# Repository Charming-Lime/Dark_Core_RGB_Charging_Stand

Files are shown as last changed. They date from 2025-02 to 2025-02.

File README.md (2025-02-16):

# Corsair Dark Core RGB Pro SE Wireless Charging Stand 
A RGB wireless charging stand for the Corsair Dark Core RGB Pro SE.

[](photos/photo1.jpg)

Designed to be printed with a single manual filament swap for the diffuser ring. 

Printed in Polymaker PolyTerra charcoal matte PLA and SUNLU transparent PLA. 

# Materials

Links are for example purposes and generics should be available from the usual amazon / ebay / Aliexpress.

## Required 
* Generic Wireless charger PCB, there are many listings on amazon and Aliexpress with the same dimensions that will work

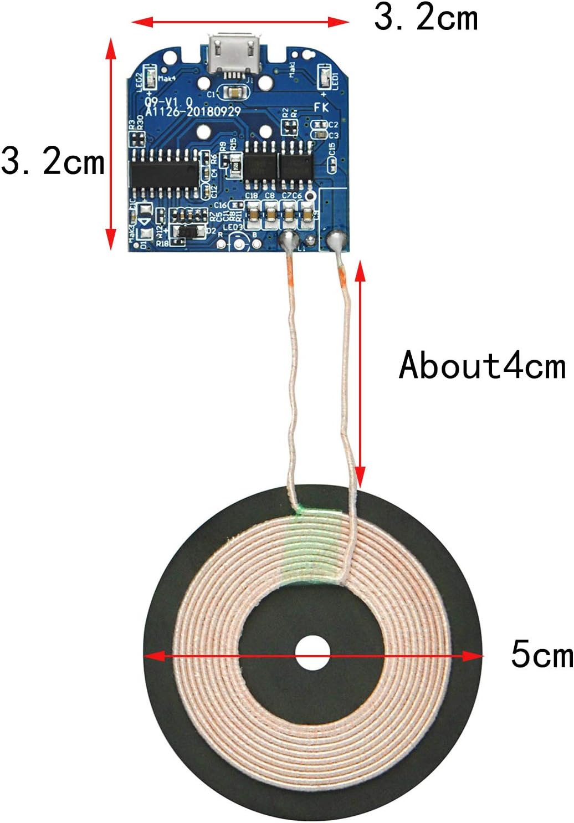
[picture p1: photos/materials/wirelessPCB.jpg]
  [](https://www.amazon.com/dp/B073W7P5T8?ref=ppx_yo2ov_dt_b_fed_asin_title)

* RP2040-zero

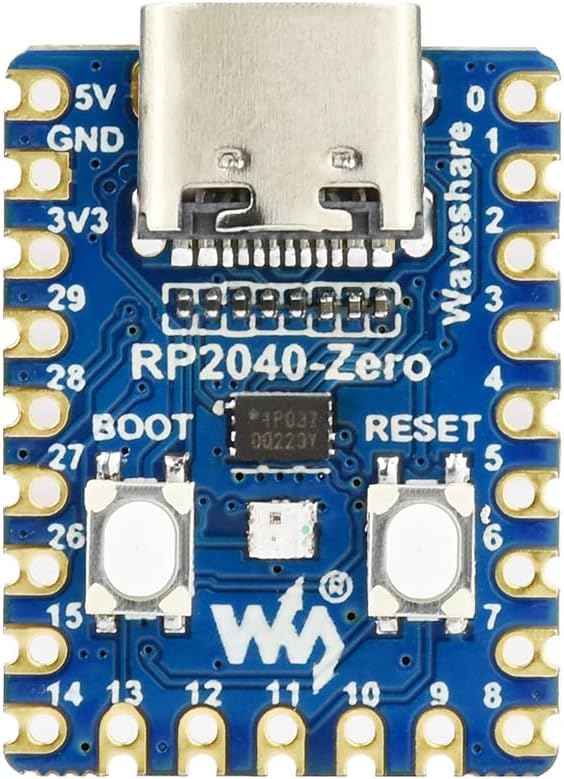
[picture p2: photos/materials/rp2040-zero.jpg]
  [](https://www.amazon.com/RP2040-Zero-High-Performance-Microcontroller-Castellated-Applications/dp/B09KZPCNPL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)
  
* USB C Fast Charge Decoy Trigger PCB set at 5V
  
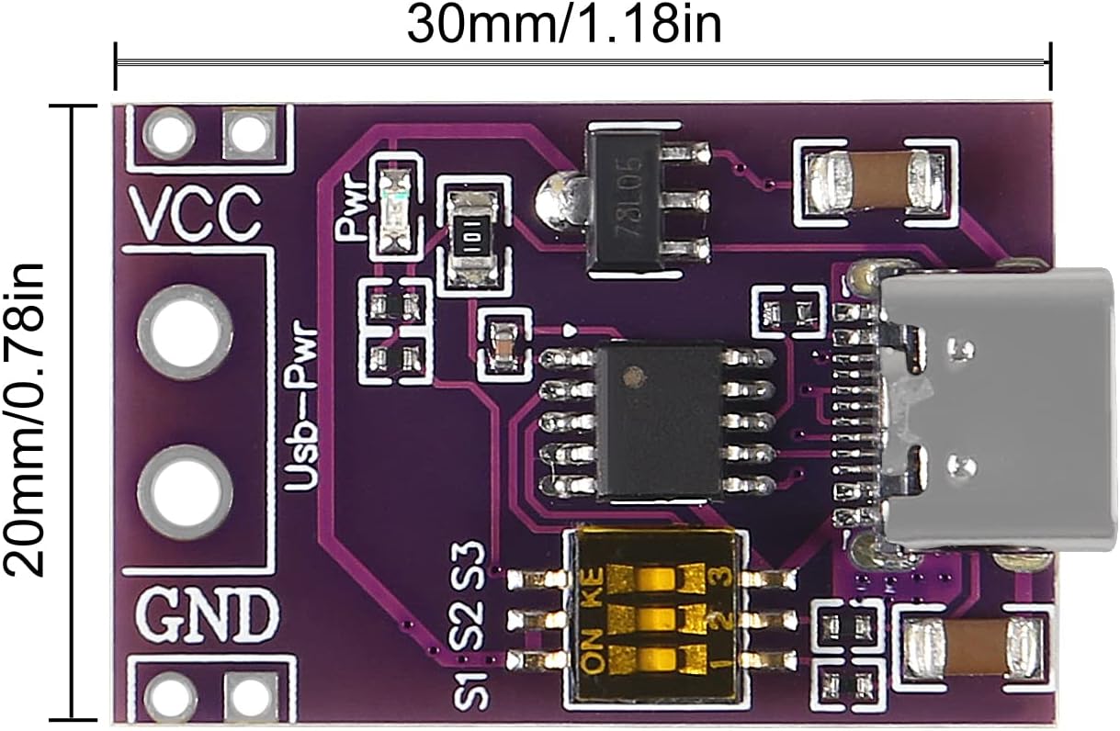
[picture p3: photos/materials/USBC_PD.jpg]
  [](https://www.amazon.com/dp/B0BTHXKM91?ref=ppx_yo2ov_dt_b_fed_asin_title)

* 5v WS2812b RGB strip, 60 LEDs/meter, cut to 18 segments
  
* Wire, heat shrink, soldering equipment
  
* 4x m3x16 self taping screws
* Stick on rubber feet.

Most of the components should be generic enough that the exact seller should not matter, but I have included exactly what I used anyway. Room is tight and most components are sized to fit snugly.

### Optional
* 10k and 20k resistor for voltage divider if you want the RGB to react while charging.
  *  Required if you want the LED on the stand to pulse when the mouse is charging.
* Hot glue
* CA glue
 
# Assembly
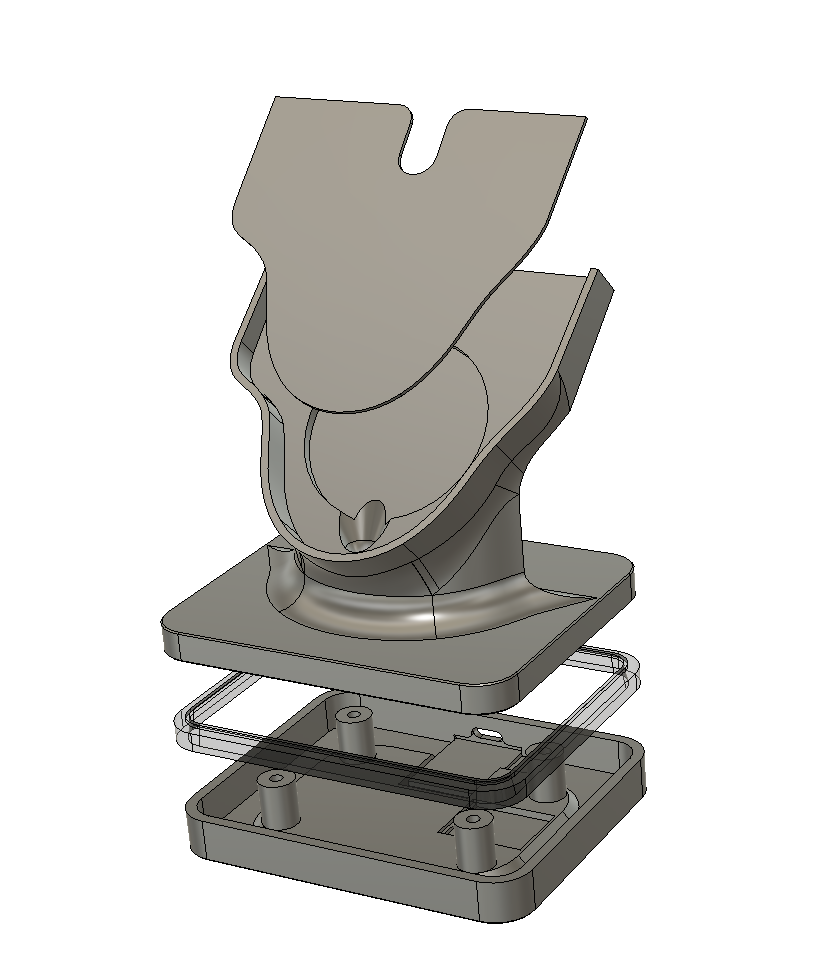
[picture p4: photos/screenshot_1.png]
[](photos/screenshot_1.png)
## Printing

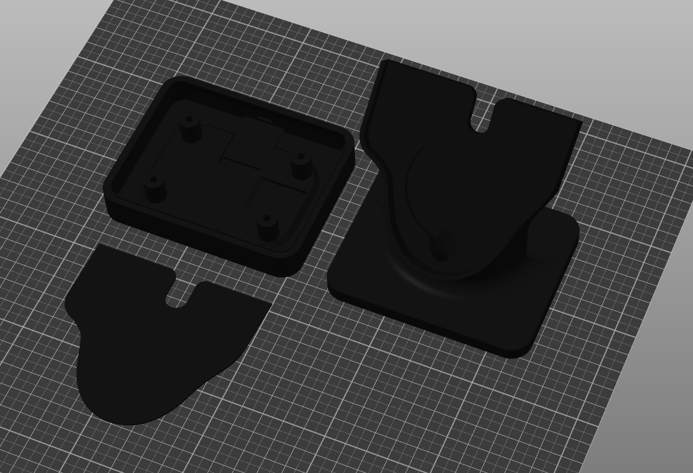
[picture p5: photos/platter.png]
[](photos/platter.png)

The charging stand is printed in 3 pieces, stand, base, and cover, I used 0.16 layer height. 
Part orientation should be as imported into the slicer. The base and diffuser get imported and sliced together, with a pause and filament swap at ~11.50mm.
Print with supports on for the holder and base. Set your support settings so the only part with supports is the cutout and screw holes. You *may* be able to get away without it depending on how good your printer is at bridging.

 ### Base
The part where the magic happens.
Transparent filament works the best for the diffuser, but a white filament should work. 
Import both the base and the diffuser and slice them together. Insert a pause command or a filament swap at 11.50mm. Be sure to thoroughly purge and clean your nozzle. If your slicer supports it change the settings for the diffuser to be no infill, 2 perimeters, and 0.2 layer height, but feel free to experiment. You are trying to strike a ballance between seeing the individual LEDs and letting light though. This 
will give you the most even defusing.

## Wiring
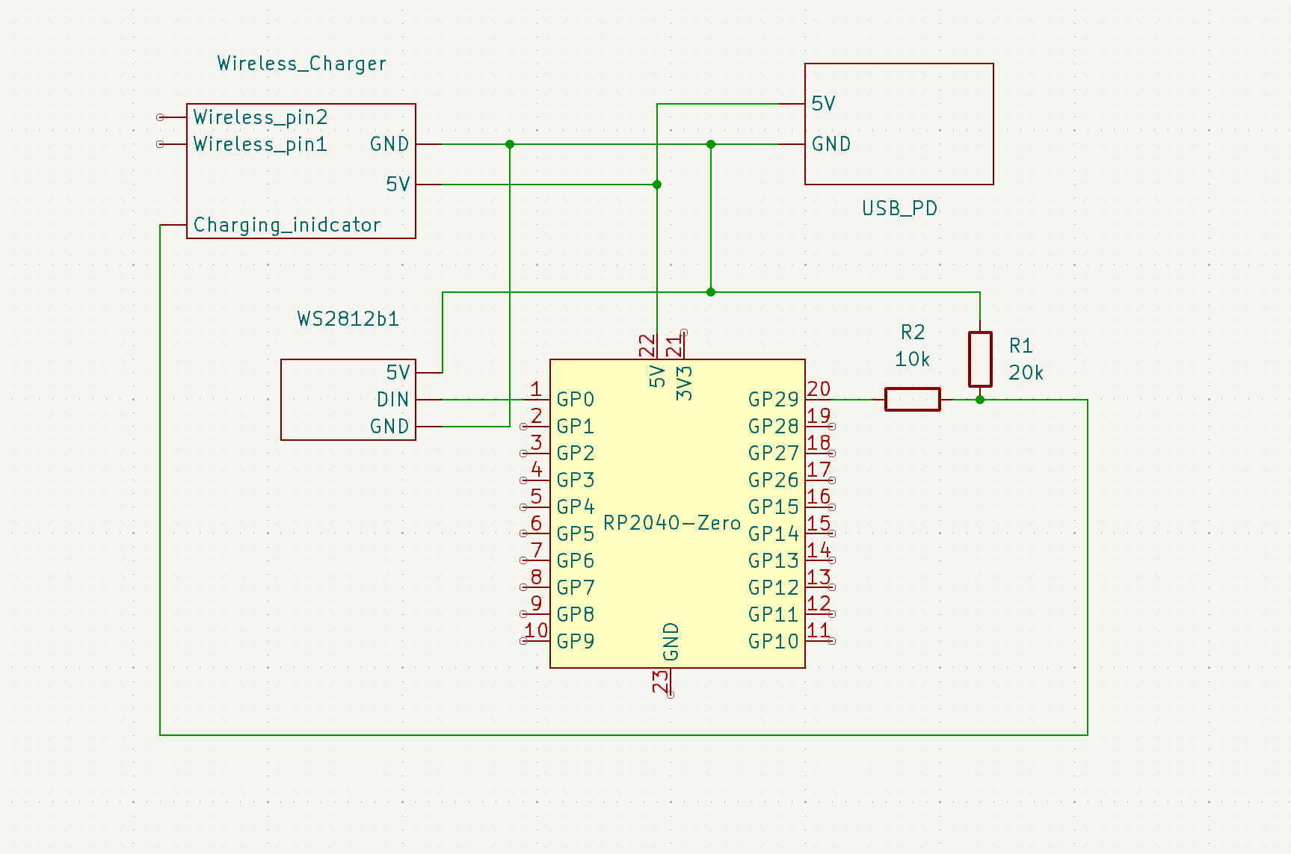
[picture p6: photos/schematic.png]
[](photos/schematic.png)

Wire the PCBs together as shown in the schematic. The LED strip should be 17 or 18 segments long. You will need to locate the 5V and GND input pins on the charging circuit board as well as the charging sense pin. In my case it was high (5v) when not charging and dropped while charging. The charging sense circuit is definitely a hack, but it works. I have included a annotated photo of which pin drops down from 5v when charging, but it should be verified with a multimeter before soldering. Keep extra wirelength to a minimum as space is tight. Be mindful of wire gauges as well, the charging circuit can pull 2A and the LEDs can draw another 1A. You will need to cut and extend the wireless charging pad wires. Use hot glue to secure the PCBs and wires and add extra insolation if needed.

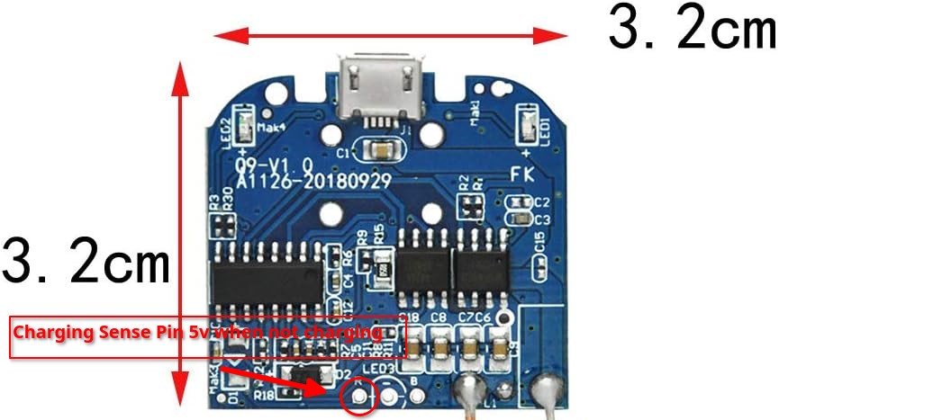
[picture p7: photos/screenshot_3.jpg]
[](photos/screenshot_1.jpg) [](photos/photo4.jpg)

## RP2040 Programing

The the included Arduino code is based on the fastLED DemoReel100 by Mark Kriegsman and is separately licensed under the The MIT License

Program the rp2040 with with included code using your method of choice, I used Arduino IDE. You will need the FastLED library installed. If you are not using the charging sense you can comment out these lines:

```
if (analogRead(chargingSignalPin)<900)
  {
    charging = true;
  }else
  {
    charging = false;
  }
  ```

## Final Assembly
Once everything is wired and tested, you can glue the wireless charge pad and cover with a few drops of CA glue, and secure the base with the 4x screws. You can either cover the holes with the rubber feet or off set them for easier disassembly.

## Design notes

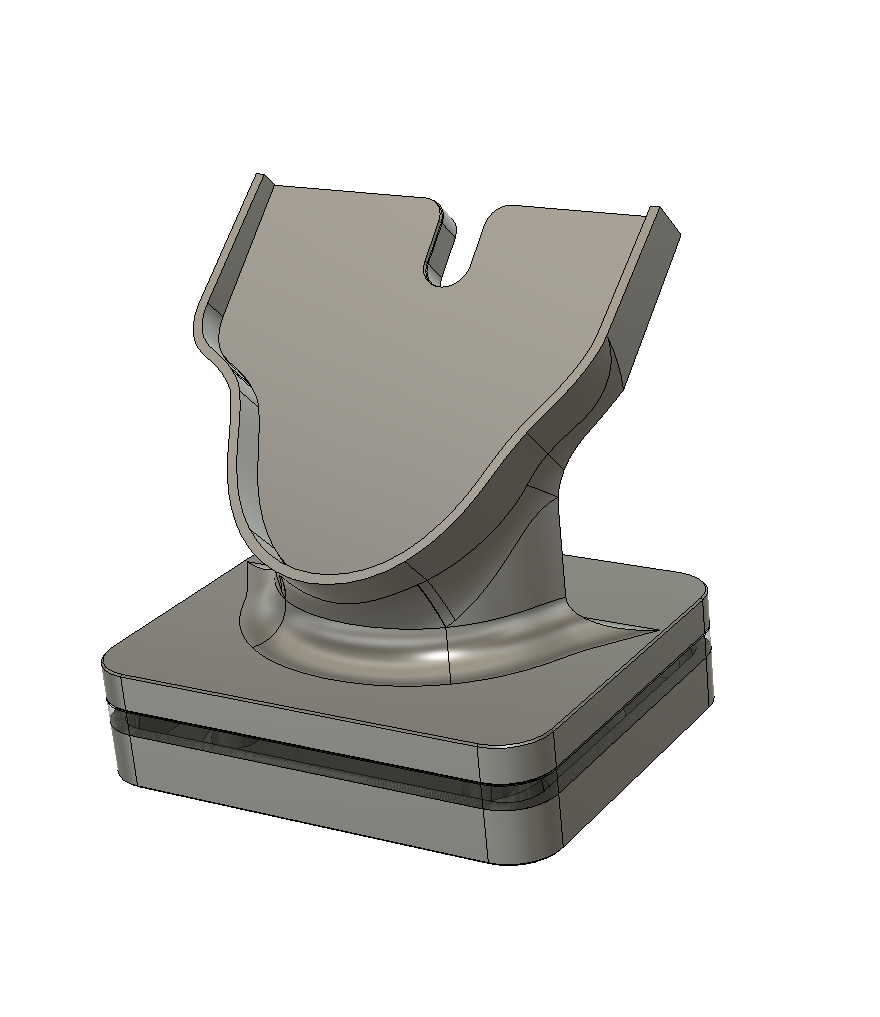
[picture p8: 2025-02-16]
photos/screenshot_2.png

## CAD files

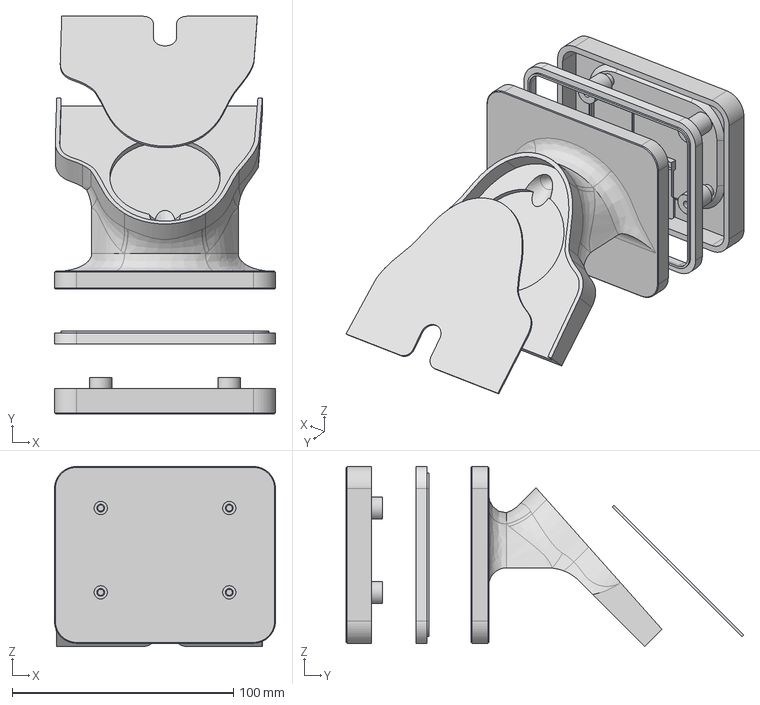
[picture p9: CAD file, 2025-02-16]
CAD/Dark core holder.step
100.0 x 179.9 x 81.5 mm

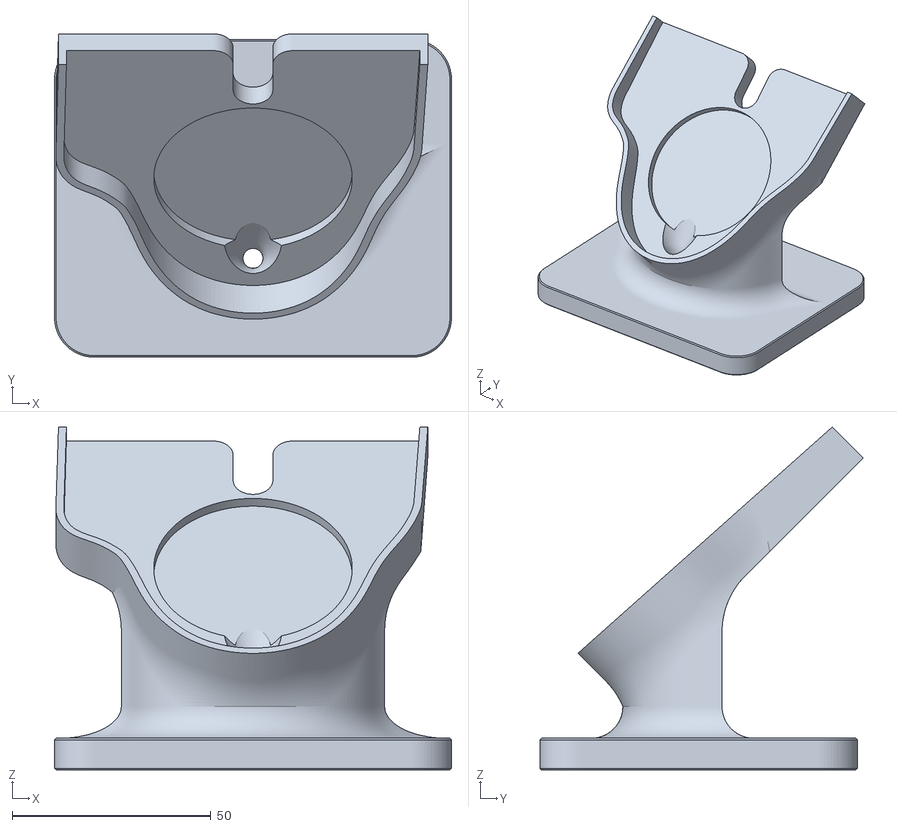
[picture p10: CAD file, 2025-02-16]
STL/Corsair_Dark_Core_Stand.stl
100.0 x 81.5 x 86.4

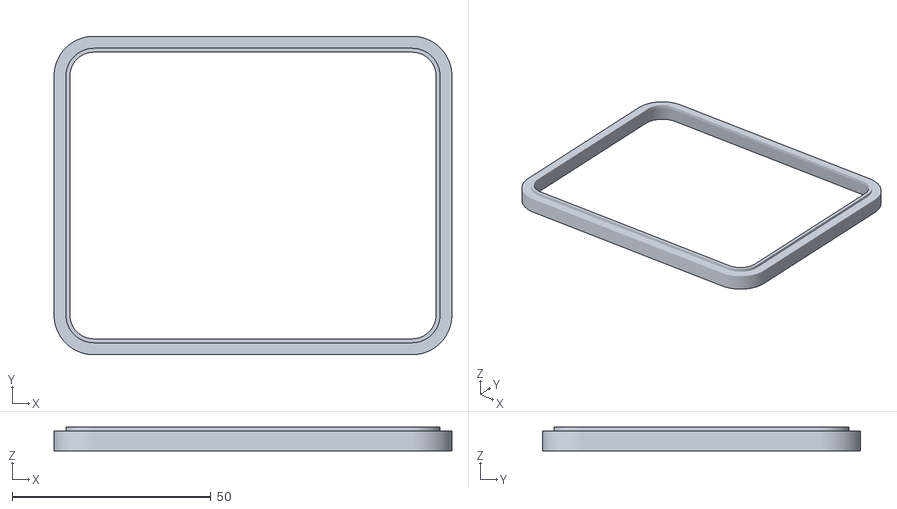
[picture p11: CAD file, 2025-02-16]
STL/Corsair_Dark_ Core_Diffuser.stl
100.0 x 80.0 x 6.00

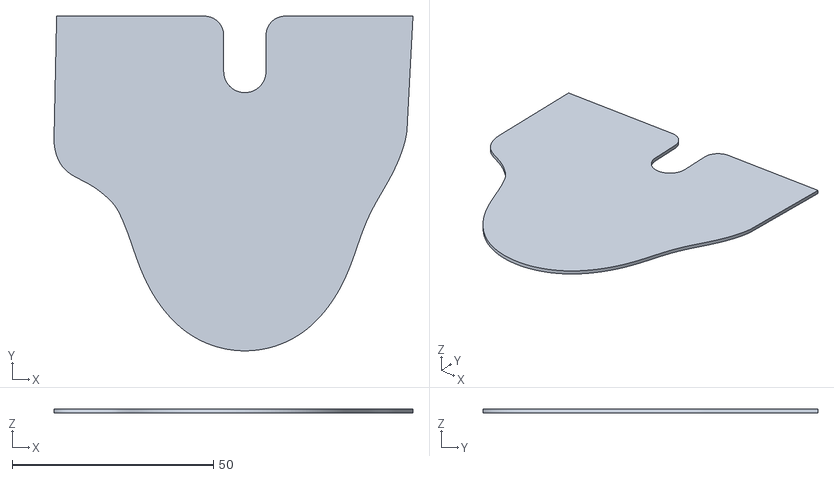
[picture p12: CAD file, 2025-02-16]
STL/Corsair_Dark_Core_Cover.stl
89.2 x 83.1 x 1.00

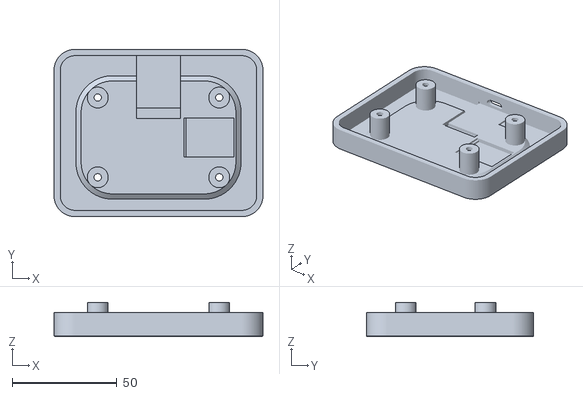
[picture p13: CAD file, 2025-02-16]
STL/Corsair_Dark_ Core_Base.stl
100.0 x 80.0 x 16.5

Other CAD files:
CAD/Dark core holder.f3d

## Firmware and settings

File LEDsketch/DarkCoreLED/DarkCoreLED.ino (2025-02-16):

//The MIT License (MIT)
//
//
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
//Based on FastLED "100-lines-of-code" demo reel
#include <ADCInput.h>
#include <FastLED.h>
#include <Adafruit_NeoPixel.h>


#define DATA_PIN    0
#define LED_TYPE    WS2811
#define COLOR_ORDER GRB
#define NUM_LEDS    19 // one more than in the stip to force a "gap" where the USBC slot is
#define MAX_BRIGHTNESS      200
#define FRAMES_PER_SECOND   120

#define chargingSignalPin A3
CRGB leds[NUM_LEDS];
Adafruit_NeoPixel onboardLED(1, 16, NEO_GRB + NEO_KHZ800);// set neopixle to use the onboard LED

typedef void (*SimplePatternList[])();

void setup() {

  delay(3000); // 3 second delay for recovery
  onboardLED.begin();
  onboardLED.show(); // Initialize onboard LED to 'off'

  Serial.begin(9600);
  // tell FastLED about the LED strip configuration
  FastLED.addLeds<LED_TYPE,DATA_PIN,COLOR_ORDER>(leds, NUM_LEDS).setCorrection(TypicalLEDStrip);

  // set master brightness control
  FastLED.setBrightness(MAX_BRIGHTNESS);
  setRanbow();
}


// List of patterns to cycle through.  Each is defined as a separate function below.

SimplePatternList gPatterns = { rainbow, rainbowWithGlitter, confetti, sinelon, juggle, bpm };

uint8_t gCurrentPatternNumber = 0; // Index number of which pattern is current
uint8_t gLastLoopPatternNumber = 0;
uint8_t gHue = 0; // rotating "base color" used by many of the patterns


bool charging = false;

uint8_t hue_speed = 20;
uint8_t breathe_speed = 20;


unsigned long startMillis; 
unsigned long currentMillis;


void loop()
{
  // Call the current pattern function once, updating the 'leds' array
  gPatterns[gCurrentPatternNumber]();
  // send the 'leds' array out to the actual LED strip
  FastLED.show();  

  // insert a delay to keep the framerate modest
 // FastLED.delay(1000/FRAMES_PER_SECOND); 

  // do some periodic updates
  EVERY_N_MILLISECONDS( hue_speed ) { gHue++; } // slowly cycle the "base color" through the rainbow

  if (analogRead(chargingSignalPin)<900)
  {
    charging = true;
  }else
  {
    charging = false;
  }

  if(charging)
  {
    onboardLED.setPixelColor(0, 100, 0, 0);
    onboardLED.show();
    EVERY_N_MILLISECONDS (breathe_speed) {addBreathe();}
  }
  else
  {
    onboardLED.clear();
    onboardLED.show();
    EVERY_N_MILLISECONDS (breathe_speed) {fadeIn();}
  }
}

void setRanbow()
{
  gCurrentPatternNumber = 0;
}

uint8_t low_brightness = 10;
uint8_t current_brightness=MAX_BRIGHTNESS;
int8_t brightnesStep = 1;

void addBreathe()
{
  if(current_brightness >= MAX_BRIGHTNESS || current_brightness <= low_brightness)
  {
    brightnesStep *= -1;
  }

  FastLED.setBrightness(current_brightness + brightnesStep);
  current_brightness += brightnesStep;
}

void fadeIn()
{
  brightnesStep=abs(brightnesStep);
  if (current_brightness < MAX_BRIGHTNESS)
  {
    FastLED.setBrightness(current_brightness + brightnesStep);
    current_brightness += brightnesStep;
  }
}


void setRanbowGlitter()
{
  // add one to the current pattern number, and wrap around at the end
  gCurrentPatternNumber = 1;
}

void rainbow() 
{
  // FastLED's built-in rainbow generator
  fill_rainbow( leds, NUM_LEDS, gHue, 7);
}

void rainbowWithGlitter() 
{
  // built-in FastLED rainbow, plus some random sparkly glitter
  rainbow();
  addGlitter(80);
}

void addGlitter( fract8 chanceOfGlitter) 
{
  if( random8() < chanceOfGlitter) {
    leds[ random16(NUM_LEDS) ] += CRGB::White;
  }
}

void confetti() 
{
  // random colored speckles that blink in and fade smoothly
  fadeToBlackBy( leds, NUM_LEDS, 10);
  int pos = random16(NUM_LEDS);
  leds[pos] += CHSV( gHue + random8(64), 200, 255);
}

void sinelon()
{
  // a colored dot sweeping back and forth, with fading trails
  fadeToBlackBy( leds, NUM_LEDS, 20);
  int pos = beatsin16( 13, 0, NUM_LEDS-1 );
  leds[pos] += CHSV( gHue, 255, 192);
}

void bpm()
{
  // colored stripes pulsing at a defined Beats-Per-Minute (BPM)
  uint8_t BeatsPerMinute = 62;
  CRGBPalette16 palette = PartyColors_p;
  uint8_t beat = beatsin8( BeatsPerMinute, 64, 255);
  for( int i = 0; i < NUM_LEDS; i++) { //9948
    leds[i] = ColorFromPalette(palette, gHue+(i*2), beat-gHue+(i*10));
  }
}

void juggle() {
  // eight colored dots, weaving in and out of sync with each other
  fadeToBlackBy( leds, NUM_LEDS, 20);
  uint8_t dothue = 0;
  for( int i = 0; i < 8; i++) {
    leds[beatsin16( i+7, 0, NUM_LEDS-1 )] |= CHSV(dothue, 200, 255);
    dothue += 32;
  }
}
